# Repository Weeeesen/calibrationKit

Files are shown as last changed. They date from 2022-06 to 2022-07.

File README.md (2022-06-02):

# calibrationKit

### Requirements
- Autodesk Inventor Professional 2022
- **IMPORTANT** for threads, download the threadModeler addon (by coolOrange) see creating_screw_threads_in_autodesk_inventor_2022.pdf

### Top Level Files & Folder Structure
    calibrationKit/
    ├── .git/
    ├── calibrationKit_v1/
    │    ├── components_shared/
    │    ├── LED Filament Assembly/
    │    ├── L-frame/
    │    ├── T-wand/
    │    └── printDetails_activeMarker.xlsx
    ├── calibrationKit.ipj
    ├── creating_screw_threads_in_autodesk_inventor_2022.pdf
    └── README.md

### Notes
- Clone git repo into desired folder
- Open calibrationKit.ipj (project) file
- Proceed to open desired ipt (part) or iam (assembly) files
- *Without opening project file, Inventor will constantly open dialog box to notify that file is not in the same project (because every user will have different location for their inventor project, commonly in C:/Users/<user>/Documents/Inventor/ or some sort)

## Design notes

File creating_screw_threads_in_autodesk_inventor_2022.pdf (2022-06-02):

To create threads:
We need to download and install the autodesk app called threadModeler by a publisher called coolOrange.
BUT this app only supports up to Inventor version 2020
So to workaround, search for "Alicia Clark" in this page https://apps.autodesk.com/INVNTOR/en/Detail/Index?id=2540506896683021779&appLang=en&os=Win64&autostart=true and follow her instructions.

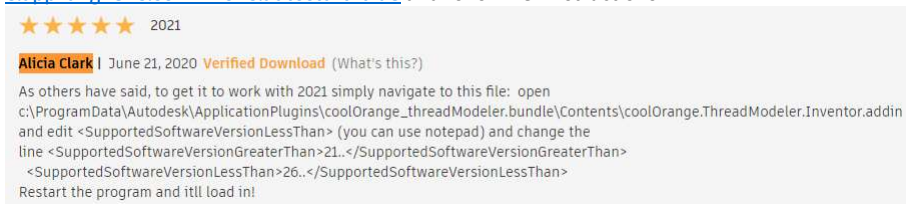
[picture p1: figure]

Basically…
Go to this link in the Explorer "C:\ProgramData\Autodesk\ApplicationPlugins

\coolOrange_threadModeler.bundle\Contents\" 1.

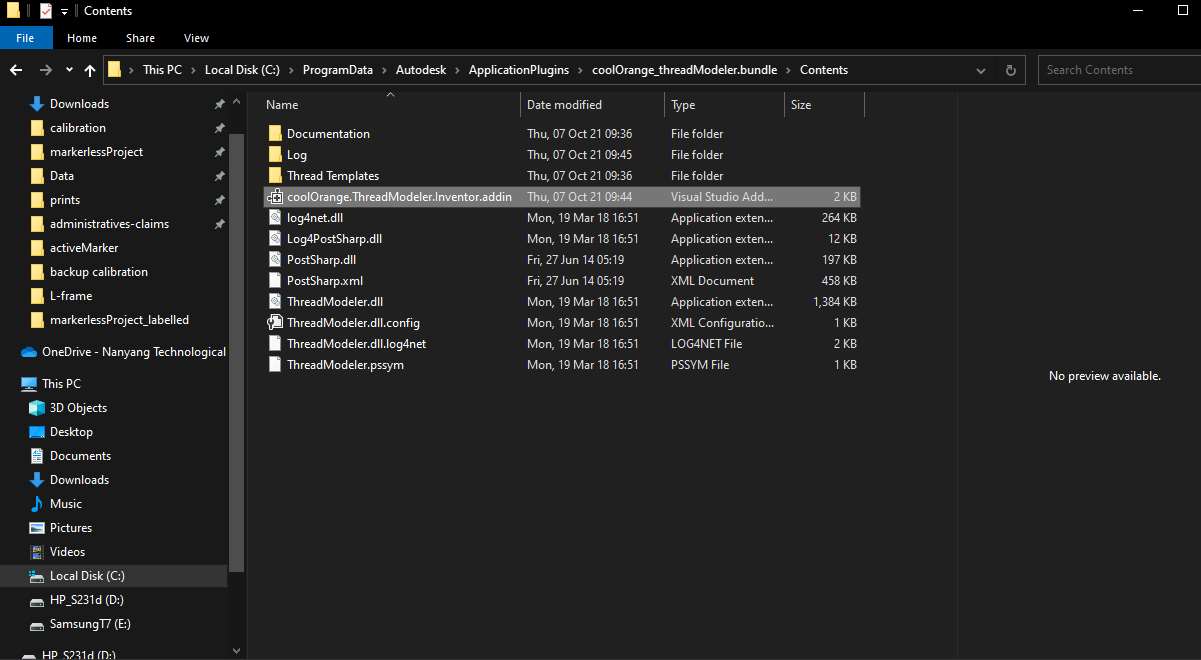
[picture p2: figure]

Open this file "coolOrange.ThreadModeler.Inventor.addin" and change the ..LessThan.. value to 27.

2.

# Creating screw threads in Autodesk Inventor 2022

Thursday, October 7, 2021 09:46

hardware-activeMarker Page 1

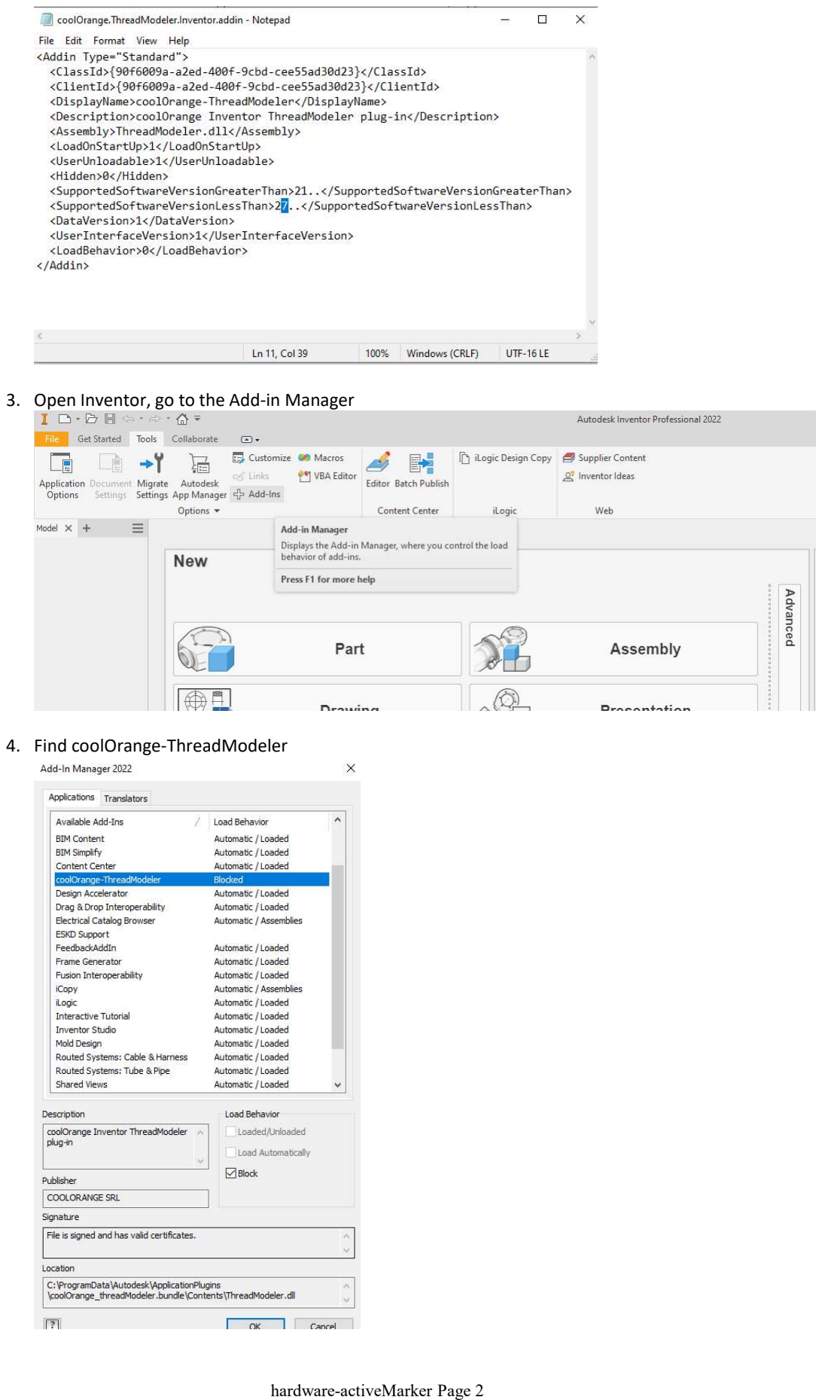
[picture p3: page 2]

### 3. Open Inventor, go to the Add-in Manager

### 4. Find coolOrange-ThreadModeler

hardware-activeMarker Page 2

### 5. Change load behavior to this

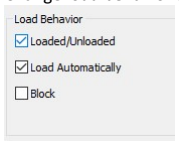
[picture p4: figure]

### 6. Should see this in the list

### 7. After that coolOrange should appear in the ribbon

================================================================================== ==============

This youtube video shows a longer version of the workaround and includes how to use it too. Thread Modeling Inventor 2022

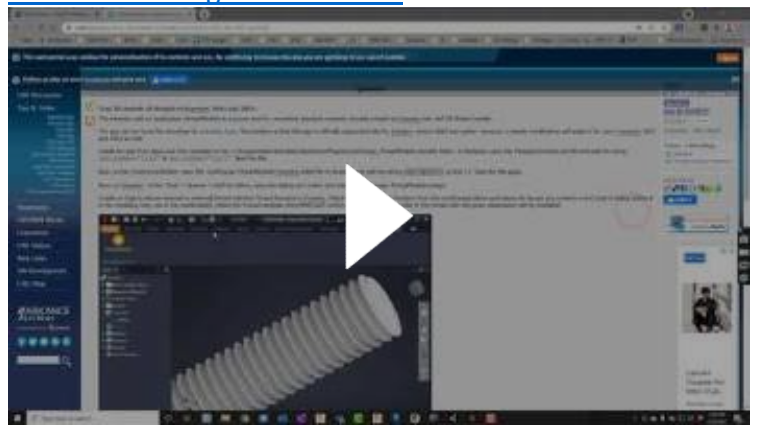
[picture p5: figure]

hardware-activeMarker Page 3

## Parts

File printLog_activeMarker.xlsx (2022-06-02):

 |  |  |  |  |  |  |  |  |  |  |  |  |  |  | Support
SN | Part(s) | flow (%) | ext temp (°C) | bed temp (°C) | infill rate (%) | infill overlap (%) | travel speed (mm/s) | retraction min. dist. (mm) | Layer height | Wall thickness | Spiralize | Enable layer fill | Reduce a rough surface | Initial layer fill type | Range | fill rate | dist. XY | dist. Z | angle | Base | filament | Remarks | More Remarks
M01 | 0.5mm marker | 100 | 210 | 60 | 50 | 50 | 100 | 2 | 0.2 | 1.6 | No | Yes | No | Line | No |  |  |  |  | Brim | cubicon PLA+
M02 | 0.5mm marker | 100 | 210 | 60 | 50 | 50 | 100 | 2 | 0.2 | 1.6 | No | Yes | No | Line | Everywhere | 15 | 0.7 | 0.15 | 45 | Brim | cubicon PLA+ | Added some extension to slot 7mm carbon rod in. The slot needs to factor in tolerance, current print slightly too small. Expanding 0.2mm diameter for next print
M03 | 0.5mm marker | 100 | 217 | 65 | 50 | 15 | 30 | 1 | 0.2 | 1.6 | No | Yes | No | Line | Everywhere | 15 | 0.7 | 0.15 | 45 | Brim | cubicon PLA+
M04 | 0.5mm marker | 100 | 210 | 60 | 50 | 50 | 100 | 2 | 0.2 | 1.6 | No | Yes | No | Line | Everywhere | 15 | 0.7 | 0.15 | 45 | Brim | cubicon PLA+ | Same as M02 (reprinted)
M05 | 0.5mm marker | 100 | 210 | 60 | 50 | 50 | 100 | 2 | 0.2 | 0.4 | No | Yes | No | Line | Everywhere | 15 | 0.7 | 0.15 | 45 | Brim | cubicon PLA+ | Wall thickness seems to have no effect in a size like this
M06 | 0.5mm marker | 100 | 210 | 60 | 50 | 50 | 100 | 2 | 0.2 | 1.6 | No | Yes | Yes | Line | Everywhere | 15 | 0.7 | 0.15 | 45 | Brim | cubicon PLA+ | For some reason setting "spiralize" to Yes will result in an error. Ignore that option for this print and see if "Reduce a rough surface" helps with smoothing out the sides
M07 | 0.5mm marker | 100 | 210 | 60 | 50 | 50 | 100 | 2 | 0.2 | 1.6 | No | Yes | No | Line | Everywhere | 10 | 0.7 | 0.15 | 45 | Brim | cubicon PLA+
M08 | 0.5mm marker full sphere | 100 | 210 | 60 | 50 | 50 | 100 | 2 | 0.2 | 1.6 | No | Yes | No | Line | Everywhere | 15 | 0.7 | 0.15 | 45 | Raft | cubicon PLA+
M09 | 0.5mm marker full sphere | 100 | 210 | 60 | 50 | 50 | 100 | 2 | 0.2 | 1.6 | No | Yes | No | Line | No |  |  |  |  | Raft | cubicon PLA+
M10 | 0.5mm marker full sphere | 100 | 210 | 60 | 50 | 50 | 100 | 2 | 0.2 | 1.6 | No | Yes | No | Line | No |  |  |  |  | Raft | cubicon PLA+
MR01 | marker with rod for wand | 100 | 210 | 60 | 50 | 50 | 100 | 2 | 0.2 | 1.6 | No | Yes | No | Line | Everywhere | 15 | 0.7 | 0.15 | 45 | Brim | cubicon PLA+ | Rod has no extension for 7mm carbon tube | sphere side has fraying, found out I calculated the dimension wrongly, the sphere surface thickness was only 0.4mm. Adjusted for the next print to 0.8mm (2 layers walled sphere)
MR02 | marker with rod for wand | 100 | 210 | 60 | 50 | 50 | 100 | 2 | 0.2 | 1.6 | No | Yes | No | Line | Everywhere | 15 | 0.7 | 0.15 | 45 | Brim | cubicon PLA+ | Added some extension to slot 7mm carbon rod in. The slot needs to factor in tolerance, current print slightly too small. Expanding 0.2mm diameter for next print
MR03 | marker with rod for wand | 100 | 210 | 60 | 50 | 50 | 100 | 2 | 0.2 | 1.6 | No | Yes | No | Line | Everywhere | 15 | 0.7 | 0.15 | 45 | Brim | cubicon PLA+ | Slot for carbon rod still a little too small, increased 0.1mm radius in the next print to see if it is ok
MR04 | marker with rod for wand | 100 | 210 | 60 | 50 | 50 | 100 | 2 | 0.2 | 1.6 | No | Yes | No | Line | Everywhere | 15 | 0.7 | 0.15 | 45 | Brim | cubicon PLA+
MR05 | marker with rod for wand | 100 | 210 | 60 | 50 | 50 | 100 | 2 | 0.2 | 1.6 | No | Yes | No | Line | Everywhere | 15 | 0.7 | 0.15 | 45 | Brim | cubicon PLA+ | added stopper
ML01 | (raised) marker for L frame | 100 | 210 | 60 | 50 | 50 | 100 | 2 | 0.2 | 1.6 | No | Yes | No | Line | Everywhere | 15 | 0.7 | 0.15 | 45 | Brim | cubicon PLA+ | base made too thin, and forgot to add hole at the base for wire to go through
ML02 | (raised) marker for L frame | 100 | 210 | 60 | 50 | 50 | 100 | 2 | 0.2 | 1.6 | No | Yes | No | Line | Everywhere | 15 | 0.7 | 0.15 | 45 | Brim | cubicon PLA+
ML03 | (raised) marker for L frame with Keyway | 100 | 210 | 60 | 50 | 50 | 100 | 2 | 0.2 | 1.6 | No | Yes | No | Line | Everywhere | 15 | 0.7 | 0.15 | 45 | Brim | cubicon PLA+ | Counterbore + keyway
ML04 | (raised) marker for L frame with Keyway | 100 | 210 | 60 | 50 | 50 | 100 | 2 | 0.2 | 1.6 | No | Yes | No | Line | Everywhere | 15 | 0.7 | 0.15 | 45 | Brim | cubicon PLA+ | Increase counterbore size to 8mm, factoring in print tolerance. Print failed as the side of the keyway seems fucked and one of the key in the middle looks messed up too
ML05 | (raised) marker for L frame with Keyway | 100 | 210 | 60 | 50 | 50 | 100 | 2 | 0.2 | 1.6 | No | Yes | No | Line | Everywhere | 15 | 0.7 | 0.15 | 45 | Brim | cubicon PLA+ | reprint ML04 but position the keys below the base of the marker with min 1cm gap for the brim. ML04 prints the key in the middle and looks like this is the cause of failure
ML06 | (raised) marker for L frame with Keyway | 100 | 210 | 60 | 50 | 50 | 100 | 2 | 0.2 | 1.6 | No | Yes | No | Line | Everywhere | 15 | 0.7 | 0.15 | 45 | Brim | cubicon PLA+ | taper base
ML07 | (raised) marker for L frame with Keyway - tapered | 100 | 210 | 60 | 50 | 50 | 100 | 2 | 0.2 | 1.6 | No | Yes | No | Line | Everywhere | 15 | 0.7 | 0.15 | 45 | Brim | cubicon PLA+ | ML06 tapered wrong side. Adjusted for this print. Working now.
ML08 | (raised) marker for L frame with Keyway - tapered | 100 | 210 | 60 | 50 | 50 | 100 | 2 | 0.2 | 1.6 | No | Yes | No | Line | Everywhere | 15 | 0.7 | 0.15 | 45 | Brim | cubicon PLA+ | Increase counterbore depth by increasing base thickness
ML09 | (raised) marker for L frame with Keyway - tapered | 100 | 210 | 60 | 50 | 50 | 100 | 2 | 0.2 | 1.6 | No | Yes | No | Line | Everywhere | 15 | 0.7 | 0.15 | 45 | Brim | cubicon PLA+ | add small chamfer at the top edges, moved the keyway inward by 1mm to add some thickness toward the outer edge
C01 | corner piece | 100 | 210 | 60 | 50 | 50 | 100 | 2 | 0.2 | 1.6 | No | Yes | No | Line | Everywhere | 15 | 0.7 | 0.15 | 45 | Brim | cubicon PLA+
C02 | corner_withAlignment | 100 | 210 | 60 | 50 | 50 | 100 | 2 | 0.2 | 1.6 | No | Yes | No | Line | Everywhere | 15 | 0.7 | 0.15 | 45 | Brim | cubicon PLA+
C03 | corner_withAlignment | 100 | 210 | 60 | 100 | 50 | 100 | 2 | 0.2 | 1.6 | No | Yes | No | Line | Everywhere | 15 | 0.7 | 0.15 | 45 | Brim | cubicon PLA+ | adjust infill to 100%
B01 | battery and buck converter enclosure draft | 100 | 210 | 60 | 50 | 50 | 100 | 2 | 0.2 | 1.6 | No | Yes | No | Line | Everywhere | 15 | 0.7 | 0.15 | 45 | Brim | cubicon PLA+ | draft, just to see if dimensions fit. Found out need to raise height for battery because of the wires. Other than that, tolerance seems acceptable
B02 | battery and buck converter enclosure | 100 | 210 | 60 | 50 | 50 | 100 | 2 | 0.2 | 1.6 | No | Yes | No | Line | Everywhere | 15 | 0.7 | 0.15 | 45 | Brim | cubicon PLA+ | first full version that includes thread for wand base. Works very well especially print quality, support surprisingly does not affect threads. Hole for sliding switch also fits perfectly after very minor post print touch up. Can follow up from this design and dimensions, adding fillet around the sides, etc.
B03 | battery and buck converter enclosure | 100 | 210 | 60 | 50 | 50 | 100 | 2 | 0.2 | 1.6 | No | Yes | No | Line | Everywhere | 15 | 0.7 | 0.15 | 45 | Brim | cubicon PLA+ | full version after testing snap fit mechanism - SHOULD work. -Didn’t work, the latch does not work. After manually cutting, seem to work but not deep enough. Adjust in the next print
B04 | battery and buck converter enclosure | 100 | 210 | 60 | 50 | 50 | 100 | 2 | 0.2 | 1.6 | No | Yes | No | Line | Everywhere | 15 | 0.7 | 0.15 | 45 | Brim | cubicon PLA+ | Adjusted latch, shortened screw by half, reduce raised thread height byt 0.8mm. Increased enclosure height for clearance with female part | Results is promising. But the cover is still tad bit too short and does not fully cover the enclosure. Can edit and reprint after the battery indicator is installed
 |  |  |  |  |  |  |  |  |  |  |  |  |  |  |  |  |  |  |  |  |  | increase enclosure width by 1mm for slightly more battery clearance when insert or remove, increased cover length a little to cover up the gaps, put a through hole for push button

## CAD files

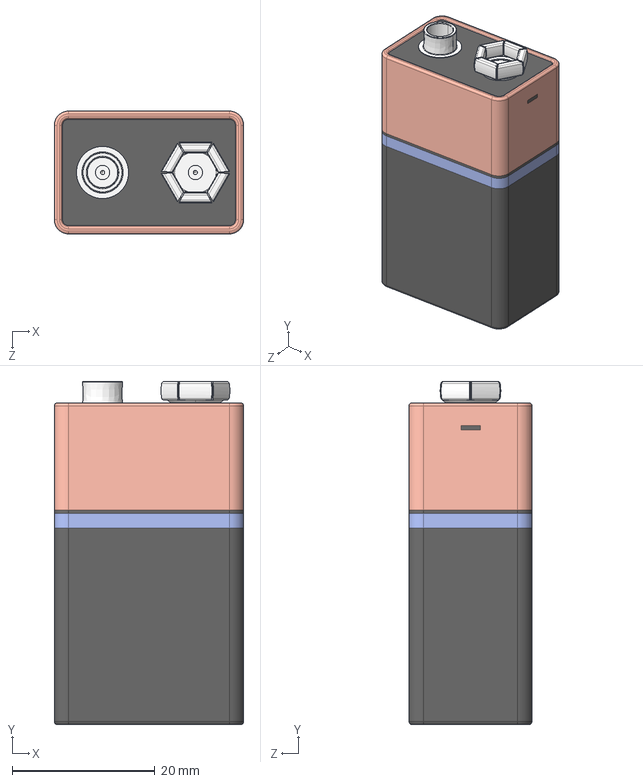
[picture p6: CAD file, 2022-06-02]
calibrationKit_v2/components/9V Battery/9V Battery.STEP
26.5 x 48.0 x 17.2 mm

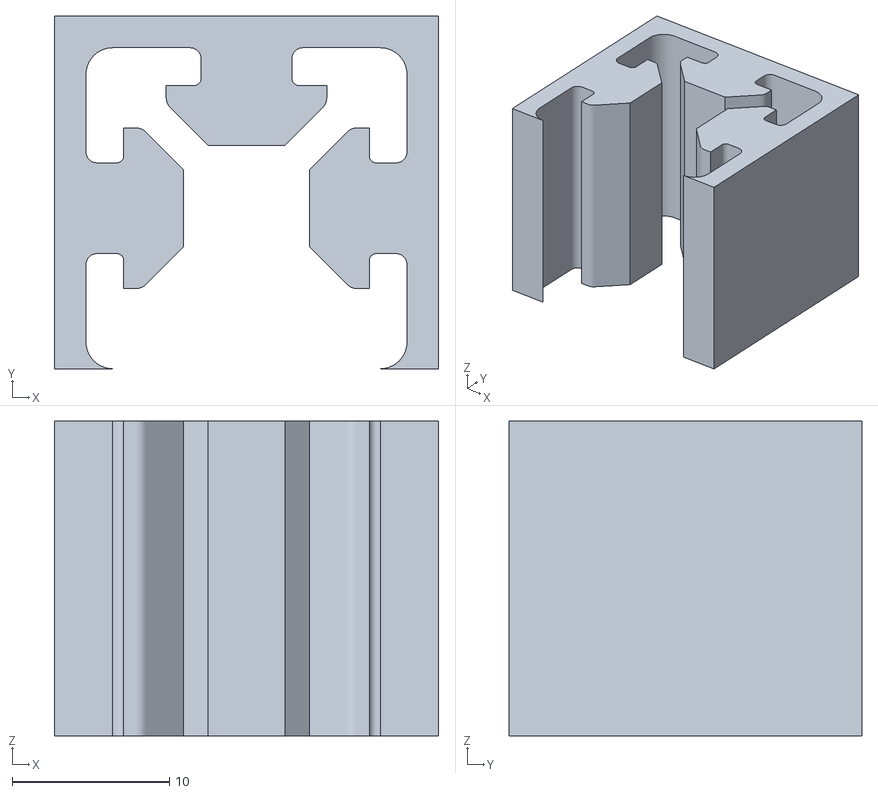
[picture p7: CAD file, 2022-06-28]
calibrationKit_v2/l-frame/slot_test.stl
24.4 x 22.4 x 20.0

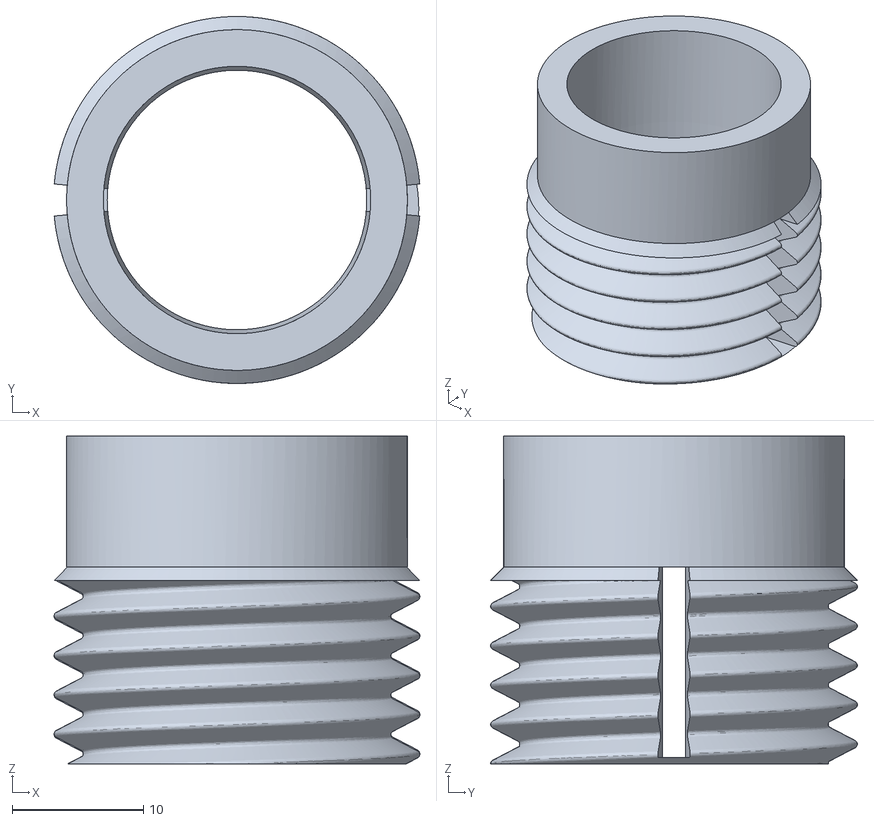
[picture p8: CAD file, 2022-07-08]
calibrationKit_v2/test_twist_friction_lock/bottomPiece2(changed thread to M22 and slot with ledge).stl
27.9 x 28.0 x 25.0

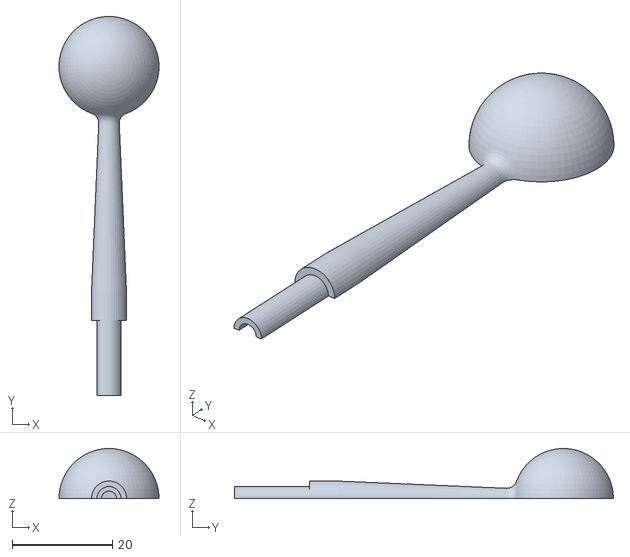
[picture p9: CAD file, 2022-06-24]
calibrationKit_v2/wand/components_wand/markerWithRodEnd_new1.stl
20.0 x 75.8 x 10.0

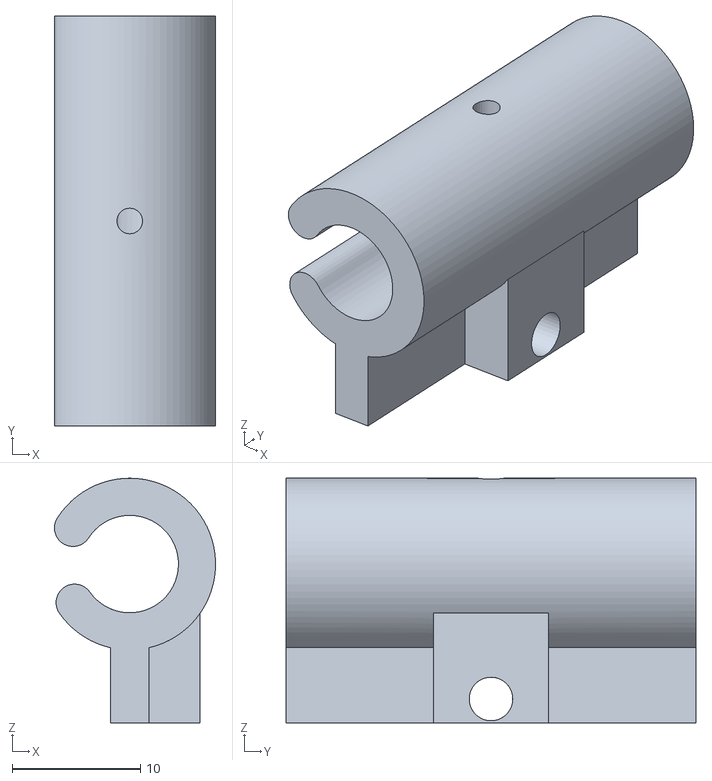
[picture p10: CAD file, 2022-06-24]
calibrationKit_v2/wand/prototype_for_circuit&connections/prototype_11(topOnly2).stl
12.6 x 32.0 x 19.1

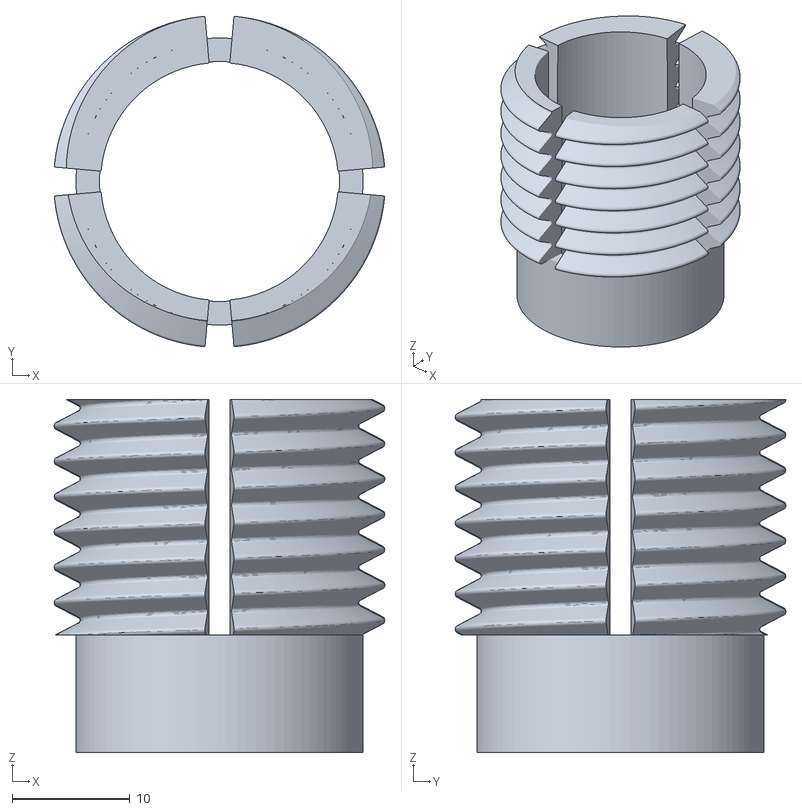
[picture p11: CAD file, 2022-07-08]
calibrationKit_v2/test_twist_friction_lock/bottomPiece2-2.stl
28.1 x 28.1 x 30.0

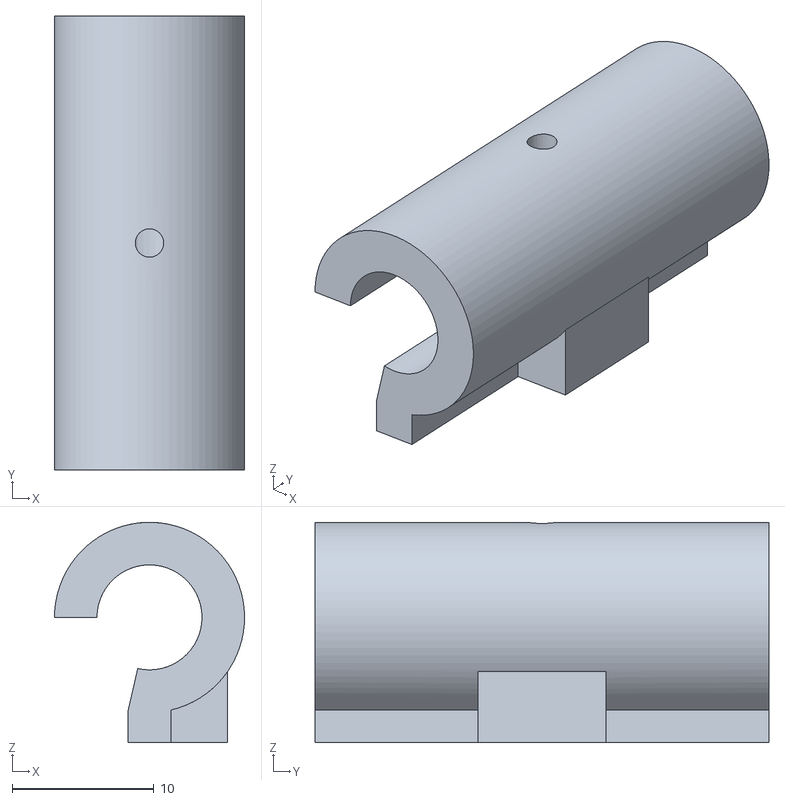
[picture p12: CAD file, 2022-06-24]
calibrationKit_v2/wand/prototype_for_circuit&connections/prototype_12_1(topOnly).stl
13.4 x 32.0 x 15.5

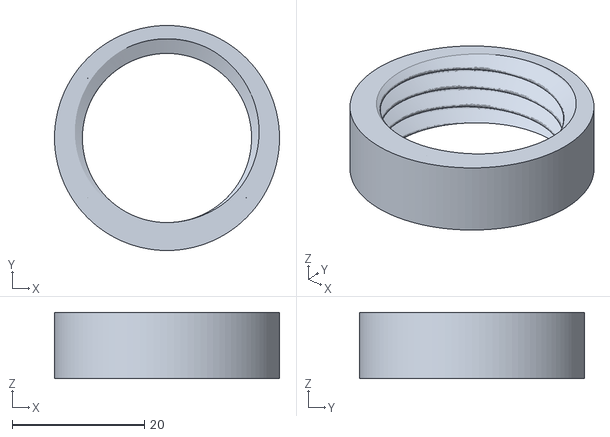
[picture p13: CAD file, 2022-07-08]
calibrationKit_v2/test_twist_friction_lock/topPiece2(changed thread to M22).stl
34.0 x 34.0 x 10.0

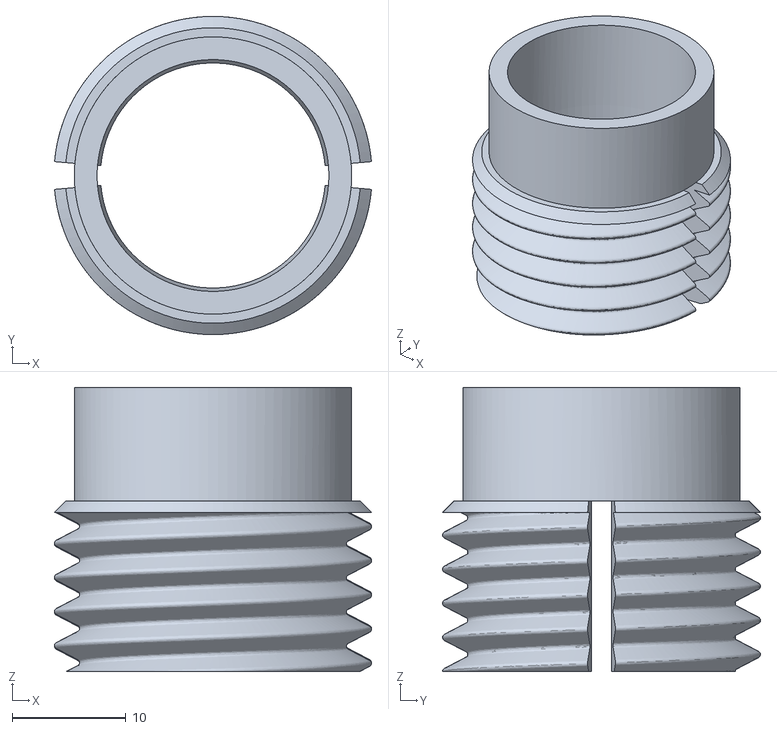
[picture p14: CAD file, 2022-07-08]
calibrationKit_v2/test_twist_friction_lock/bottomPiece2(changed thread to M22).stl
27.9 x 28.0 x 25.0

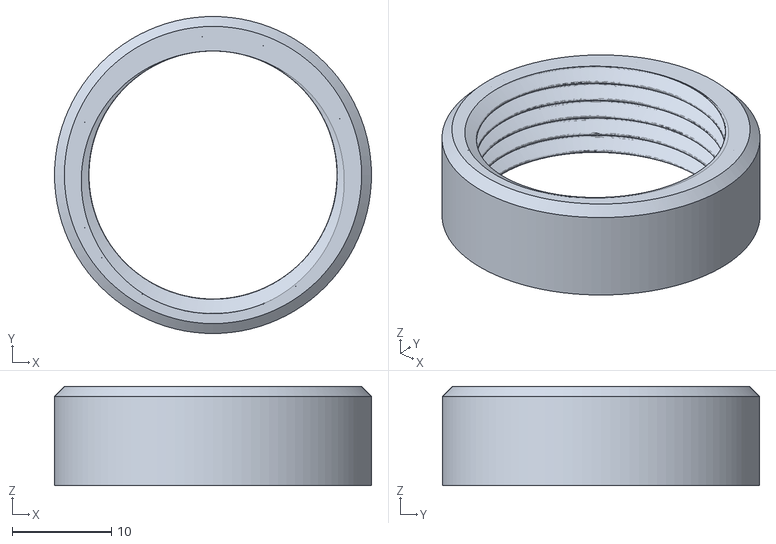
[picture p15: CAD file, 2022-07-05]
calibrationKit_v2/test_twist_friction_lock/topPiece.stl
32.0 x 32.0 x 10.0

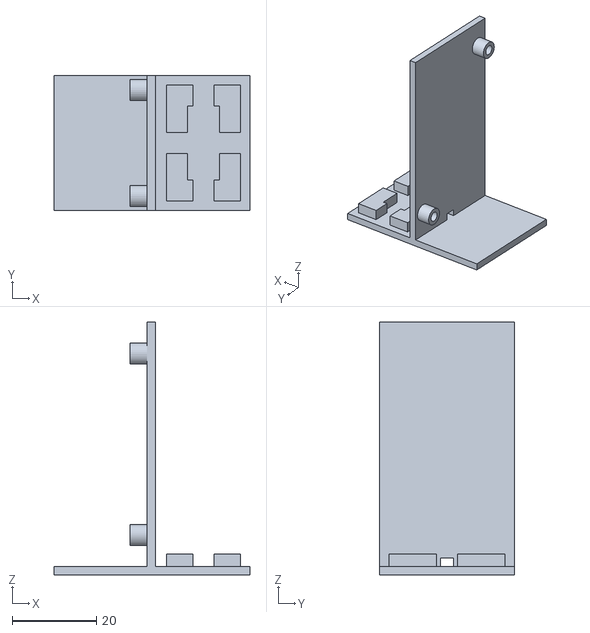
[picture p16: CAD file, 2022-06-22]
calibrationKit_v2/wand/prototype_for_circuit&connections/prototype_5_testPart1.stl
46.4 x 32.0 x 60.0

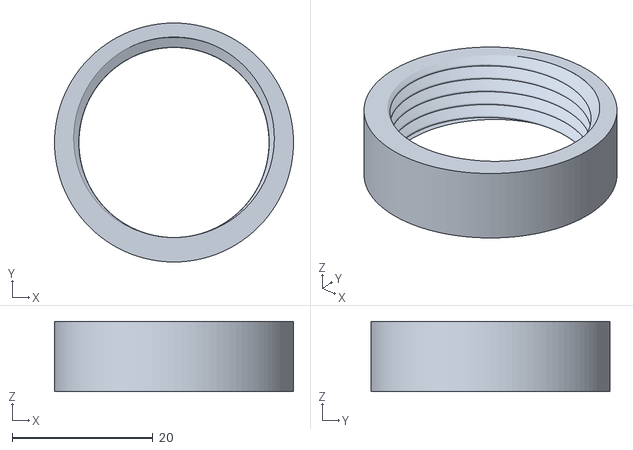
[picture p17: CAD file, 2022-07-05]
calibrationKit_v2/test_twist_friction_lock/topPiece2.stl
34.0 x 34.0 x 10.0

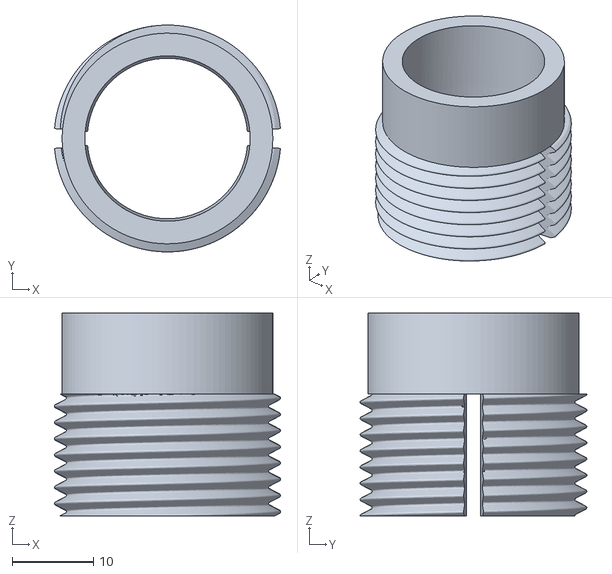
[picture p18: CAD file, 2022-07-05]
calibrationKit_v2/test_twist_friction_lock/bottomPiece2.stl
27.9 x 28.0 x 25.0

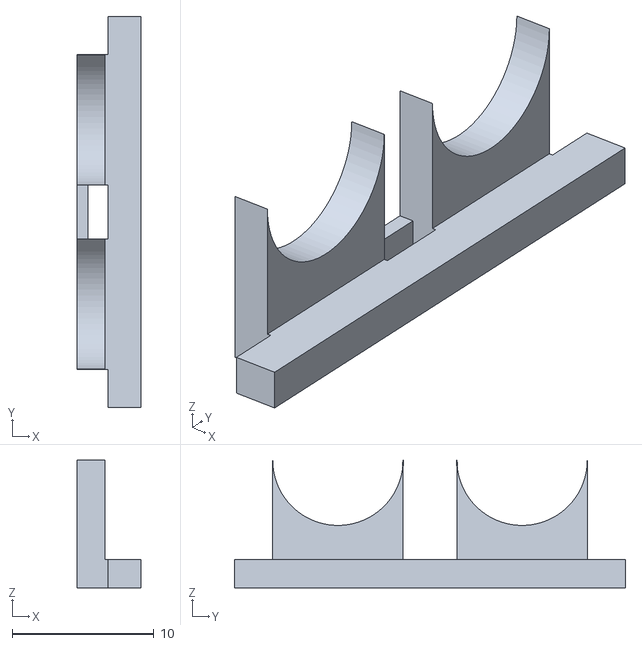
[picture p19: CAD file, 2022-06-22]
calibrationKit_v2/wand/prototype_for_circuit&connections/prototype_10_2.stl
4.55 x 27.6 x 9.00

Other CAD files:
calibrationKit_v2/test_twist_friction_lock/bottomPiece.stl
calibrationKit_v2/wand/prototype_for_circuit&connections/prototype_5_batteryPart.stl
calibrationKit_v2/wand/prototype_for_circuit&connections/prototype_5_sliderPart.stl
calibrationKit_v1/L-frame/components_L-frame/OldVersions/_LframeAssembly.0001.dwg
calibrationKit_v1/L-frame/_LframeAssembly.iam
calibrationKit_v1/L-frame/components_L-frame/2020 Aluminum profile - 370mm.ipt
calibrationKit_v1/L-frame/components_L-frame/2020 Aluminum profile - 590mm.ipt
calibrationKit_v1/L-frame/components_L-frame/2020 Aluminum profile bracket.ipt
calibrationKit_v1/L-frame/components_L-frame/2020 Profile Endcap/2020 profile endcap.ipt
calibrationKit_v1/L-frame/components_L-frame/2020 Profile Endcap/2020 profile endcap.stl
calibrationKit_v1/L-frame/components_L-frame/2020 Profile Endcap/2020 profile endcap2.stl
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

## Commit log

2022-06-02 add all files and folders
    [11V 3S Lipo Battery.ipt, 2020 Aluminum profile - 370mm.ipt, 2020 Aluminum profile - 590mm.ipt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]
2022-06-02 add calibrationKit_v2 folder; move and renamed printLog
    [3296W_V3.ipt, 9V Battery.STEP, BOARD_XL6009_V1.ipt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]
2022-06-22 more iterations of prototyping
    [3296W_V3.ipt, 9V Battery.STEP, 9V Battery.ipt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]
2022-06-24 added more iterations of wand design
    [PVC_conduit.ipt, Part1.0001.ipt, _WandAssembly.0003.iam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]
2022-06-28 updated wand and l-frame prototyping
    [2020 Aluminum profile - 590mm.0006.ipt, 2020 Aluminum profile - 590mm.ipt, Part1-1-split.ipt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]
2022-07-05 added test design for twist lock
    [Assembly1.0015.iam, Assembly1.iam, Assembly2.0001.iam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]
2022-07-08 more iterations for twist_friction_lock design
    [Assembly2.0001.iam, Assembly2.0005.iam, Assembly2.iam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]
